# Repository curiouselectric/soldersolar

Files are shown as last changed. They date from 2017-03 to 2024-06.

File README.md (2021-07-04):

# Solder Solar
Design and instructions for a simple DIY solar powered torch.

# Overview
This is a very simple soldering kit to build a solar powered torch.
The unit has a small solar panel which recharges an ultra-capacitor.
There are two LEDs, one white and one red, which are powered by the energy in the ultra-capacitor.

The ultra-capacitor is 0.47F which stores enough charge for around 20 mins of white light, or around 1 hour of red light.

This kit is designed as an introduction to solar power and also soldering.

This kit can also be used as a small power supply for other projects (requiring a 3-5.5V power supply). This could be used for very low power monitoring nodes.

This repository contains:

* Instructions
* Schematics 
* PCB design
* Parts list

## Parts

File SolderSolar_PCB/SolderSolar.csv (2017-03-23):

Reference | Value | Footprint | Datasheet
C1 | 0.47F | REInnovationFootprint:C_0_47F_SuperCap
D1 | 1N5819 | REInnovationFootprint:TH_Diode_1
D2 | RED | REInnovationFootprint:TH_LED-5MM_larg_pad_90degrees
D3 | WHITE | REInnovationFootprint:TH_LED-5MM_larg_pad_90degrees
P1 | SOLAR_V | matts_components:SIL-2_wide_lg_pad
P2 | LOGO1 | CuriousElectric3:CEC_Globe_10mm_FCU
P3 | LOGO2 | CuriousElectric3:TCEC_Words_13mm
P4 | PCB | REInnovationFootprint:PV_50x30mmEdgeCut
P5 | LOGO3 | CuriousElectric3:TCEC_Words_13mm FCu
R1 | 330 | REInnovationFootprint:TH_Resistor_1
R2 | 120 | REInnovationFootprint:TH_Resistor_1
SC1 | PV_CELL | REInnovationFootprint:PV_50x30mm_NoOutline
SW1 | RED | REInnovationFootprint:TH_FRONT_SW
SW2 | WHITE | REInnovationFootprint:TH_FRONT_SW

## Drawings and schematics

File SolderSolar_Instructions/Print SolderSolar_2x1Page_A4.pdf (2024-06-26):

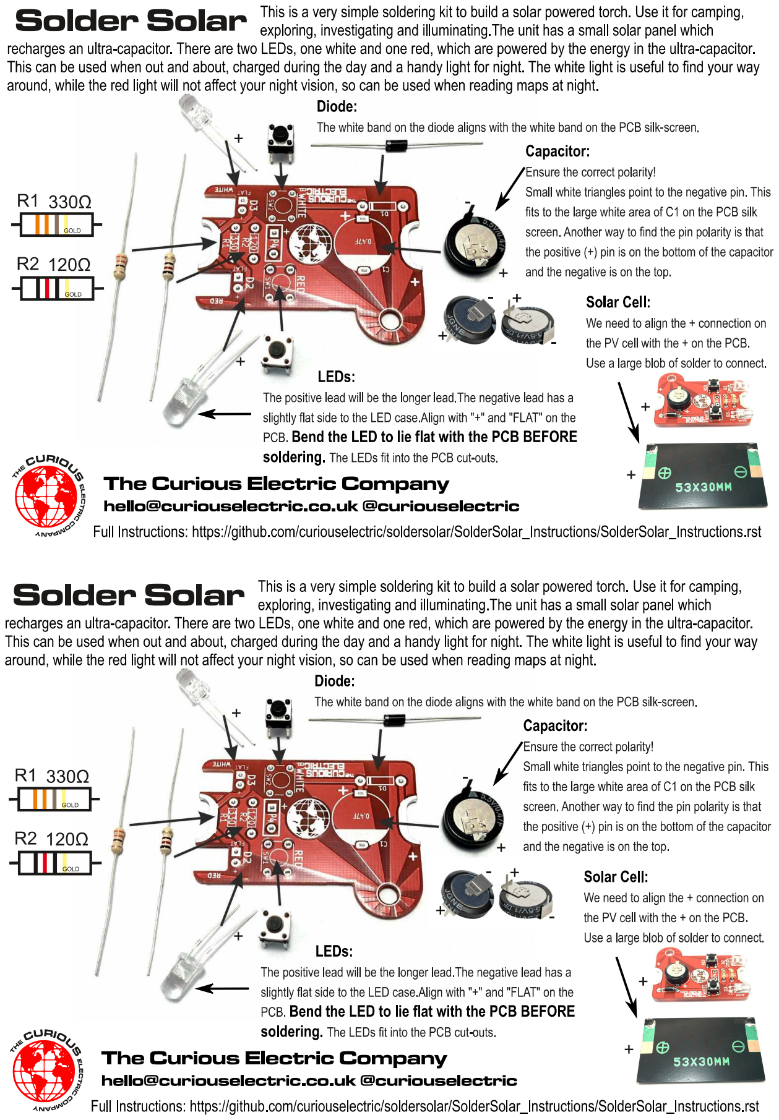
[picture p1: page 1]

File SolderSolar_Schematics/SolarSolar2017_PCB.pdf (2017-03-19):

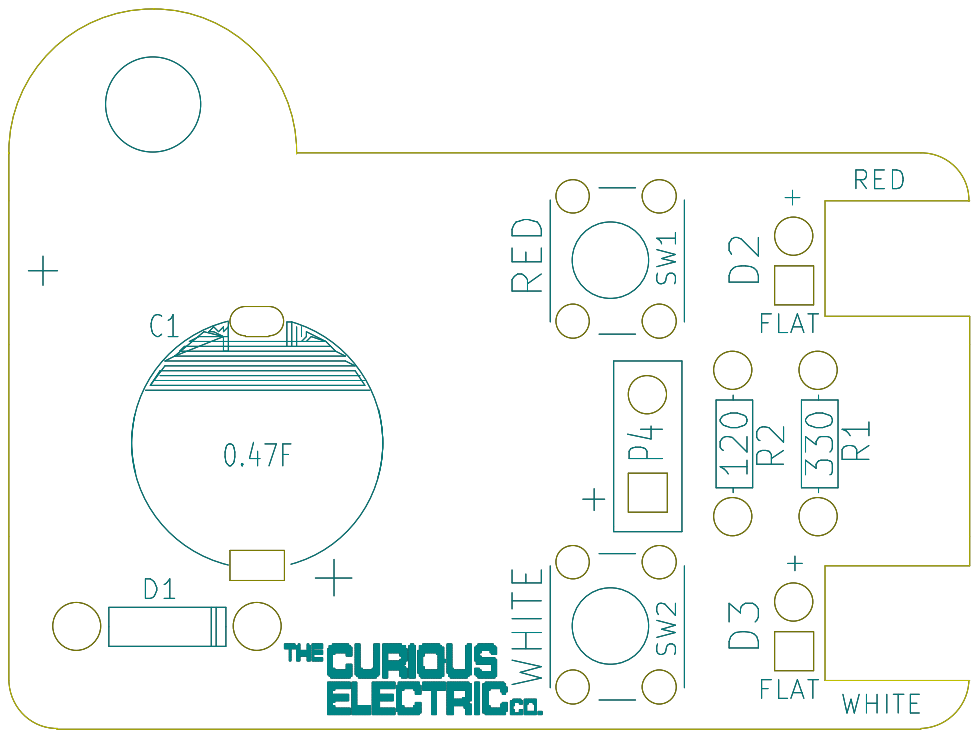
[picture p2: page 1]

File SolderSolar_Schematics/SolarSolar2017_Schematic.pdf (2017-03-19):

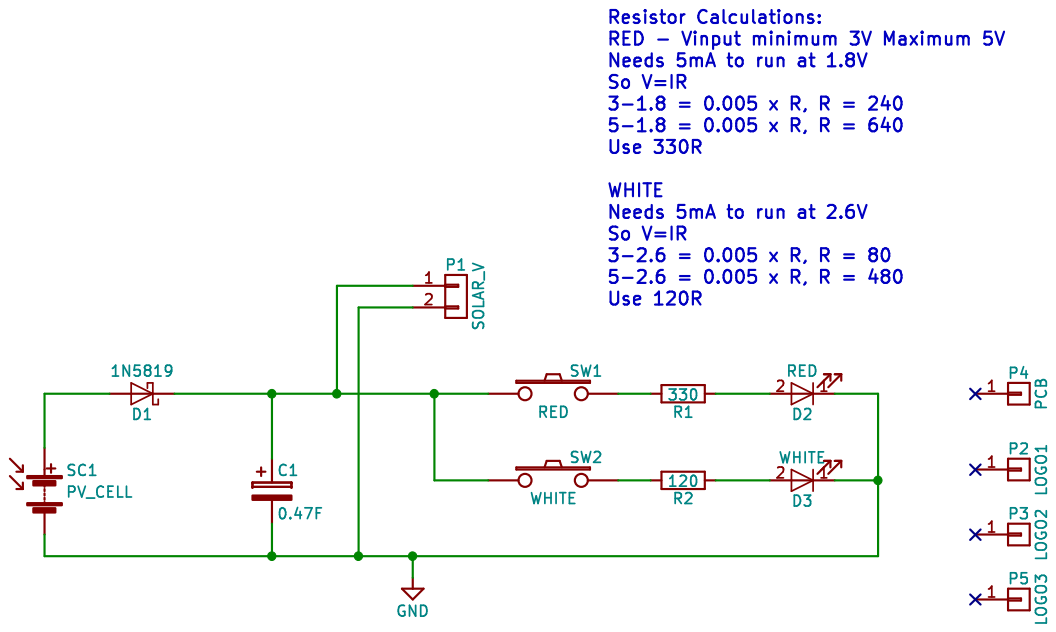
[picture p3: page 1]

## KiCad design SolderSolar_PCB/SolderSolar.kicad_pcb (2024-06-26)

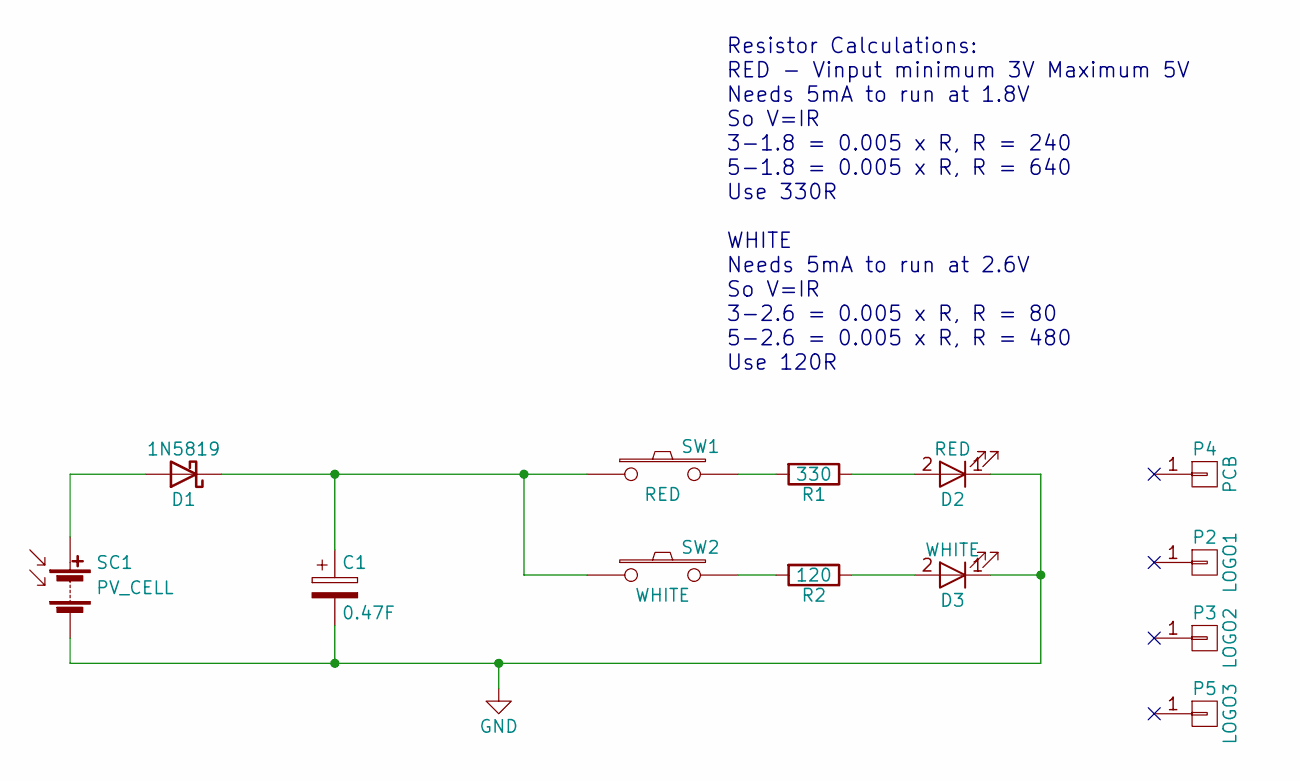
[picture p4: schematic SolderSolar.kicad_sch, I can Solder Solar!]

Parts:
C1: 0.47F; C_0_47F_SuperCap_3POS
D1: 1N5819; TH_Diode_1
D2: RED; TH_LED-5MM_larg_pad_90degrees
D3: WHITE; TH_LED-5MM_larg_pad_90degrees
P2: LOGO1; 2019_011_16_CuriousElectricCompany_Logo_Round_Logo_No_words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
P3: LOGO2; TCEC_Words_13mm
P4: PCB
P5: LOGO3; TCEC_Words_13mm FCu
R1: 330; TH_Resistor_1
R2: 120; TH_Resistor_1
SC1: PV_CELL; PV_50x30mm_NoOutline_v2
SW1: RED; TH_FRONT_SW
SW2: WHITE; TH_FRONT_SW

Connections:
GND: C1.2, D2.1 (K), D3.1 (K), SC1.2 (-)
unnamed: D1.2 (A), SC1.1 (+)
unnamed: C1.1, D1.1 (K), SW1.1, SW2.1
unnamed: D2.2 (A), R1.1
unnamed: D3.2 (A), R2.1
unnamed: R1.2, SW1.2
unnamed: R2.2, SW2.2

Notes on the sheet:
Resistor Calculations: RED - Vinput minimum 3V Maximum 5V Needs 5mA to run at 1.8V So V=IR 3-1.8 = 0.005 x R, R = 240 5-1.8 = 0.005 x R, R = 640 Use 330R WHITE Needs 5mA to run at 2.6V So V=IR 3-2.6 = 0.005 x R, R = 80 5-2.6 = 0.005 x R, R = 480 Use 120R

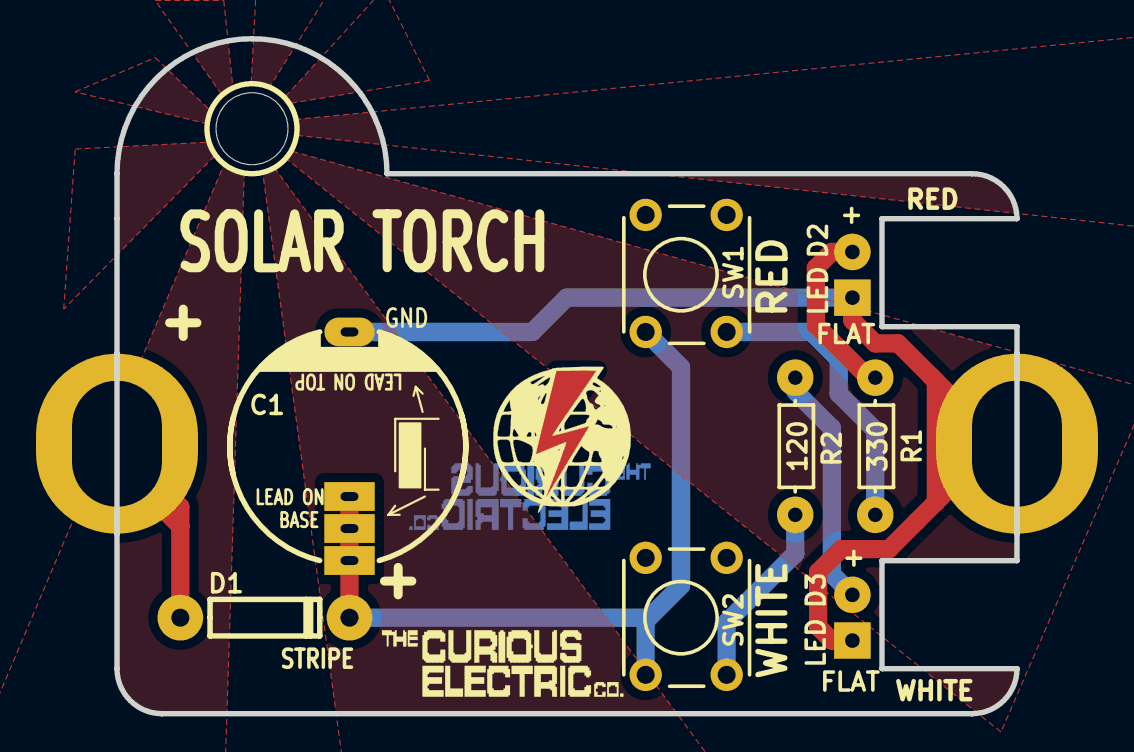
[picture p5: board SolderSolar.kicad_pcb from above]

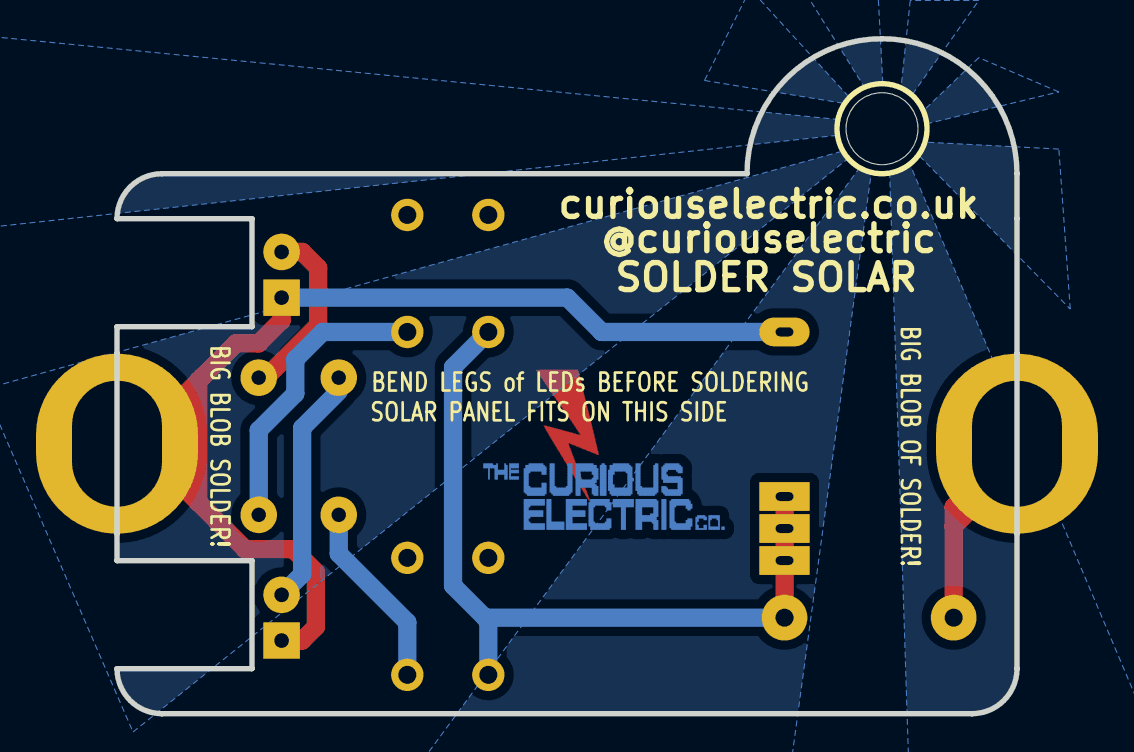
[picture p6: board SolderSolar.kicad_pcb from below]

Board: 2 copper layers, 50.0 x 37.5 mm, 13 parts (2 on the bottom side), 7 nets.

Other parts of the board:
P1: SOLAR_V; PV_50x30mmEdgeCut

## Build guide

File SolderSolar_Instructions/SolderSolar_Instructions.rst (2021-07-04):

Solder Solar
============

Design and instructions for a simple DIY solar powered torch.

This kit is designed as a **"Learn to Solder"** kit and as an introduction to **solar power**.

*By: Matthew Little*

*Date: 17th Feb 2017*

*email: hello@curiouselectric.co.uk*

Overview
-------
This is a very simple soldering kit to build a solar powered torch. Use it for camping, exploring, investigating and illuminating.

The unit has a small solar panel which recharges an ultra-capacitor.
There are two LEDs, one white and one red, which are powered by the energy in the ultra-capacitor.

This can be used when out and about, charged during the day and a handy light for night. The white light is useful to find your way around, while the red light will not affect your night vision, so can be used when reading map at night.

The ultra-capacitor is 0.47F which stores enough charge for around 20 minutes of white light, or around 1 hour of red light.

This kit can also be used as a small power supply for other projects (requiring a 3-5.5V power supply). This could be used for very low power monitoring nodes.

Kit Contents
------------

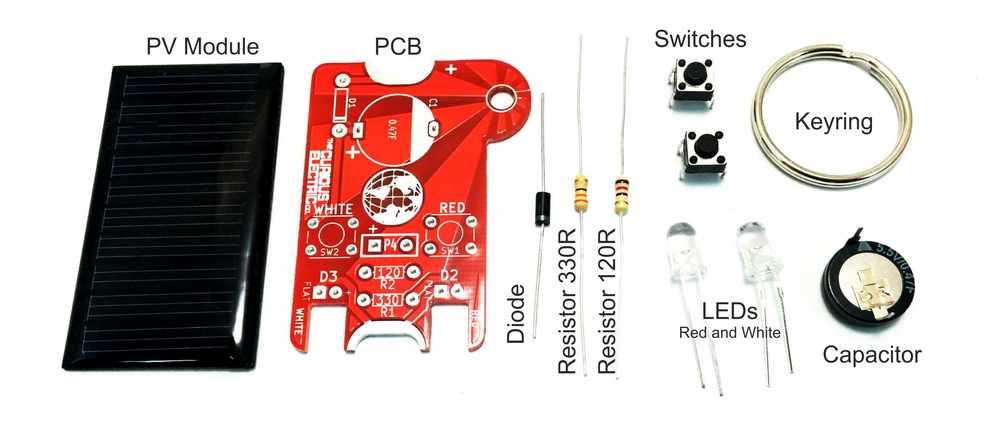
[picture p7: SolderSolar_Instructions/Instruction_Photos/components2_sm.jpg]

   
This kit contains the following parts:

+------+-----------------+--------------------------+
| REF  | Description     | Details                  |
+======+=================+==========================+
| C1   | Ultra-Capacitor | 0.47F Electrolytic       |
+------+-----------------+--------------------------+
| D1   | Diode           |                          |
+------+-----------------+--------------------------+
| D2   | LED Red         |                          |
+------+-----------------+--------------------------+
| D3   | LED White       |                          |
+------+-----------------+--------------------------+
| R1   | Resistor        |                          |
+------+-----------------+--------------------------+
| R2   | Resistor        |                          |
+------+-----------------+--------------------------+
| SC1  | Solar PV Panel  |                          |
+------+-----------------+--------------------------+
| SW1  | Switch          |                          |
+------+-----------------+--------------------------+
| SW2  |  Switch         |                          |
+------+-----------------+--------------------------+
| PCB  |  Circuit board  |                          |
+------+-----------------+--------------------------+

This photo shows where each of the components is placed on the PCB.

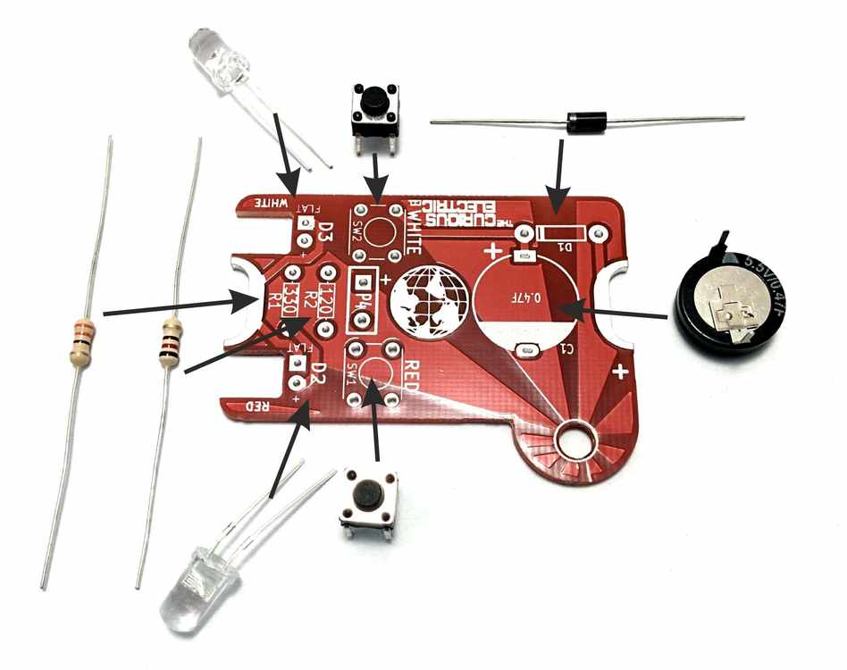
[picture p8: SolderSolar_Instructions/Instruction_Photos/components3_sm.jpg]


Tools Required
--------------
The following tools will be required:

+-----------------+--------------------------+
| Tool            | Description              |
+=================+==========================+
| Soldering Iron  | 25W+ is best             |
+-----------------+--------------------------+
| Solder          | I use lead-free solder   |
+-----------------+--------------------------+
| Side-cutter     | For cutting excess leads |
+-----------------+--------------------------+

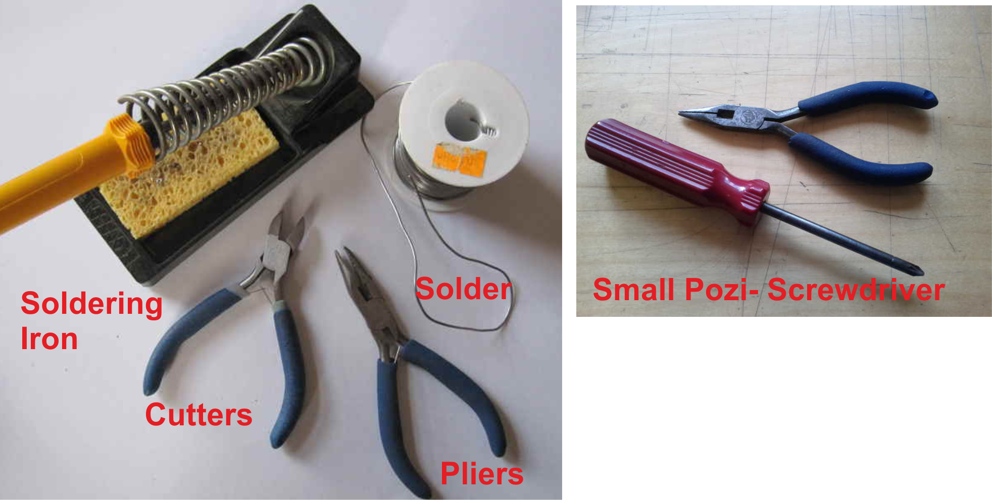
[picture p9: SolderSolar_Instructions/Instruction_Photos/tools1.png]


A useful guide for learning to solder is available here:

https://cdn.shopify.com/s/files/1/0943/8168/files/soldercomic.pdf

And a more detaileld guide is available here:

https://cdn.shopify.com/s/files/1/0943/8168/files/FullSolderComic_EN.pdf

Step 1: Solder Resistors
------------------------
There are two resistor to solder into the areas marked R1 and R2. These control the current into the LEDs and hence their brightness.

+------+-----------------+--------------------------+
| REF  | Description     | Details                  |
+======+=================+==========================+
| R1   | 330R resistor   | Orange-Orange-Brown-Gold |
+------+-----------------+--------------------------+
| R2   | 120R resistor   | Brown-Red-Black-Gold     |
+------+-----------------+--------------------------+

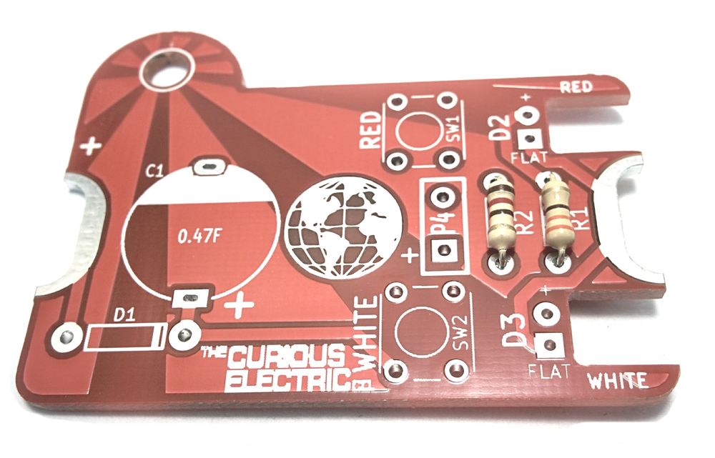
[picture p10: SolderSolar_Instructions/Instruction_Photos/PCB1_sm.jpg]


Step 2: Solder Diode
------------------------

There is one diode to solder into the holes marked D1. This is a 1N5819 Schottky diode, which is suitable for up to 1A and has a low voltage drop.
The diode allow current to pass from the solar cell to the capacitor, but not allow current to flow back to the solar cell.
This diode **must** be inserted with the correct orientation. The white band on the diode must align with the thicker white band on the PCB silk-screen.

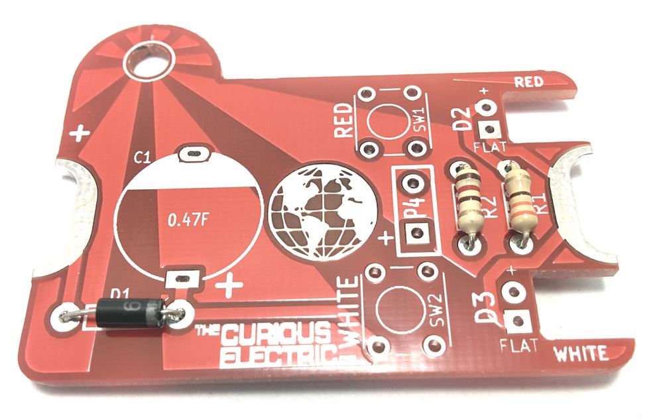
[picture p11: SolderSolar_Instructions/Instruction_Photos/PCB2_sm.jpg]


Info: The data sheet for the diode is here: https://www.diodes.com/assets/Datasheets/ds23001.pdf

Step 3: Solder Switches
------------------------
There are two switches to solder in locations SW1 and SW2.

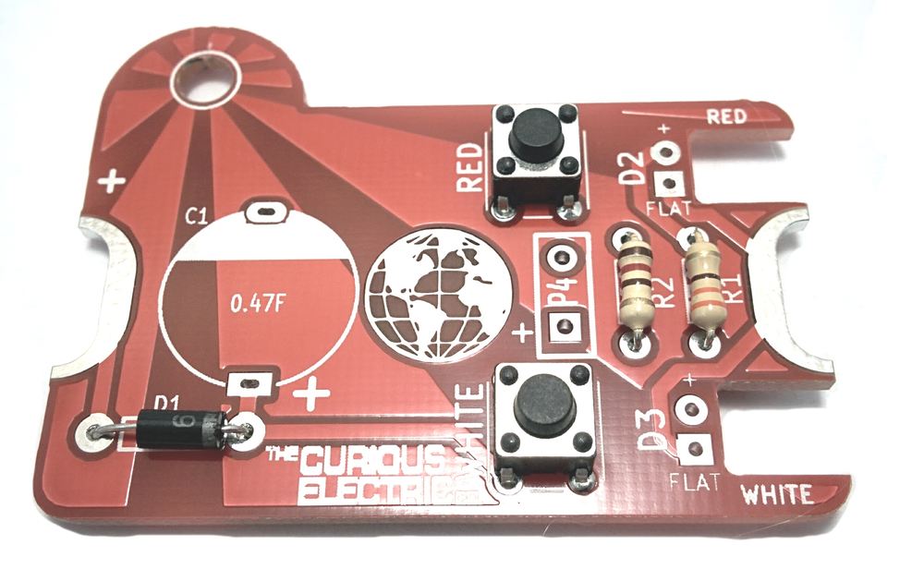
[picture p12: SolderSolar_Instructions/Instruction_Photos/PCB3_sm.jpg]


Step 4: Solder LEDs
------------------------
There are two LEDs to solder - one white and one red. These look very similar, but the red LED will have a label on it. Do not mix these up when the label taken off.

It is best to solder the white LED first, then take the label off the red LED and solder that.
You must ensure correct polarity of these LEDs.

The positive lead will be the longer lead. The negative lead has a slightly flat side to the LED case. These should align with the markings "+" and "FLAT" on the PCB.

The LEDs are designed to be bent down to align with the PCB into the cut-outs.
Please see photos for clarification.

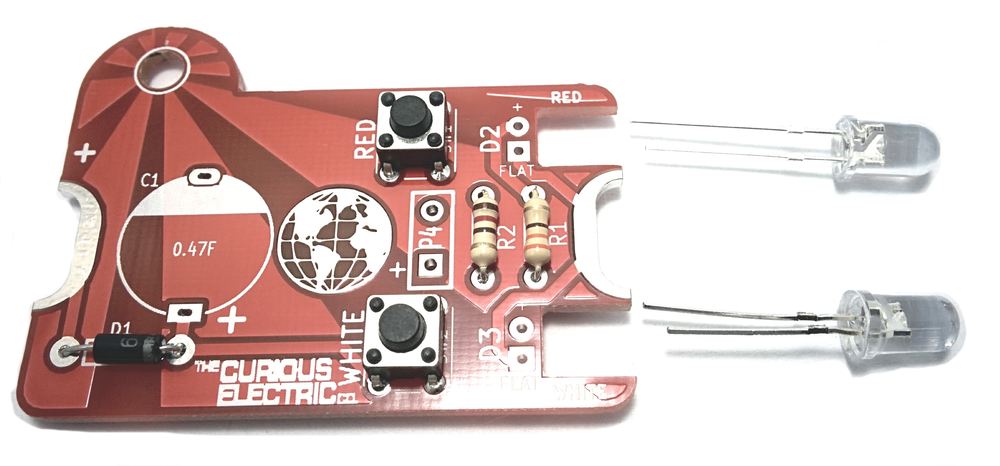
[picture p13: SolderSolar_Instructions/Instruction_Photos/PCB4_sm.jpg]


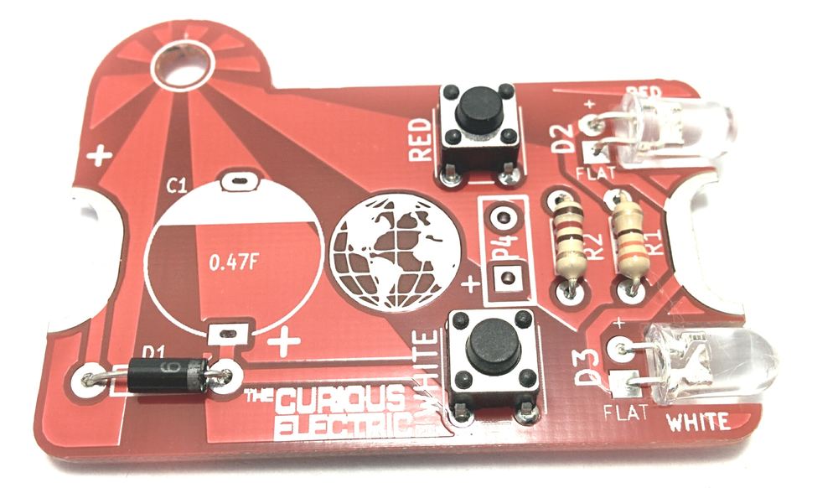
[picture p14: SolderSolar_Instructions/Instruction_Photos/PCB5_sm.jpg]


Step 5: Solder Capacitor
------------------------
The capacitor is a 0.47F ultra-capacitor. This is used to store the energy from the solar cell so it can be used later.
It is an electrolytic capacitor and you **must ensure the correct polarity**.

There are some small white triangles on the capacitor which indicate the negative pin. This pin must align with the large white area of C1 on the PCB silk screen.

Another way to find the pin polarity is that the positive (+) pin is on the bottom of the capacitor and the negative is on the top.
Please see photos for clarification.

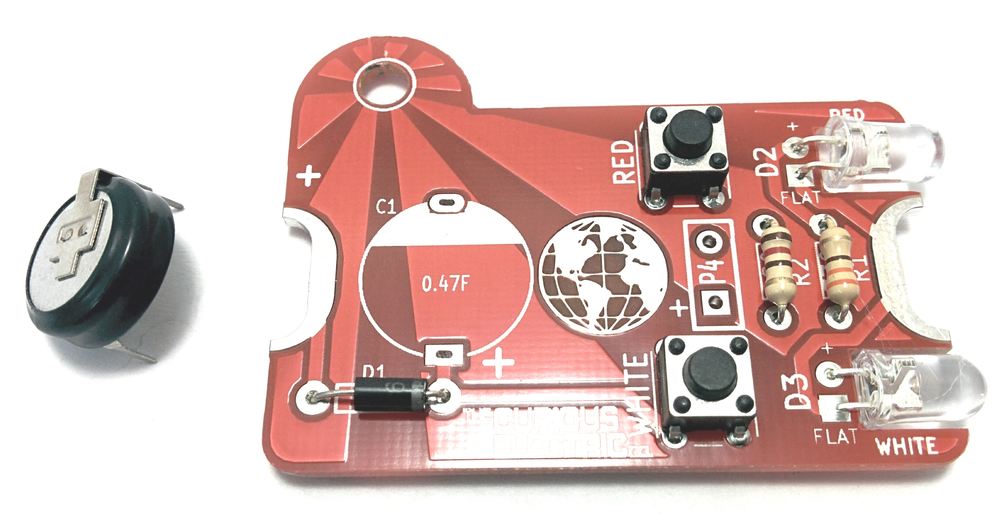
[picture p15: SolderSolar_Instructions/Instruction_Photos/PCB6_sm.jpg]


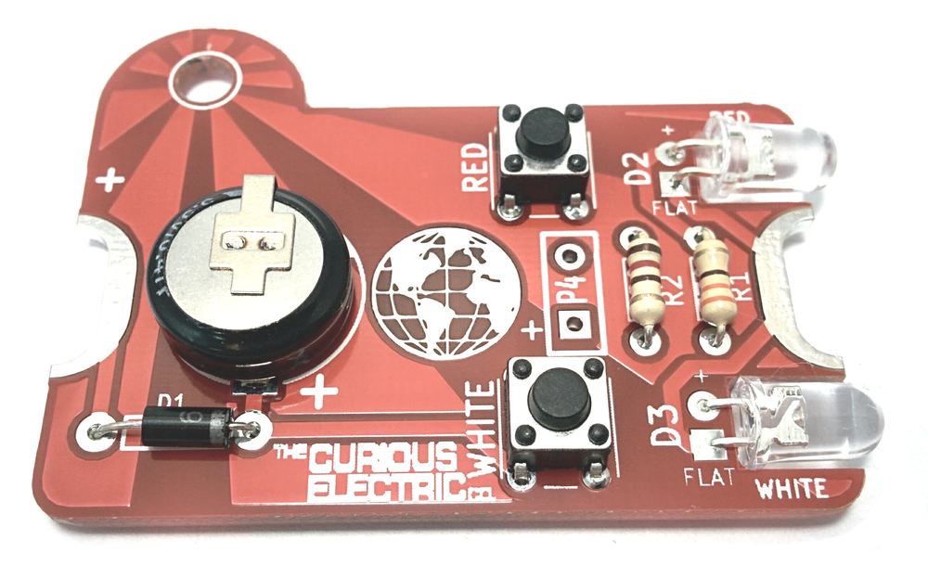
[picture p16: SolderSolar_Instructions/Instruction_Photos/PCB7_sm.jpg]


Step 6: Solder PV Cell
------------------------
The PV cell is actually a module comprised of a number of small solar PV cells. This unit has a maximum output of 5.5V and a maximum current of 30mA under ideal conditions.

The solar cell is attached to the back of the PCB and so will cover the soldering already done - please **double check** your soldering here and ensure there are not any bad connections or solder short circuits.

We need to align the + connection on the PV cell with the + on the PCB.

We need to add quite a lot of solder to make this conenction. It is best to put a blob of solder on the PV cell pad, then leave it to cool. Then align the PV cell and add more solder until the connection is made to the contacts on the edge of the PCB.

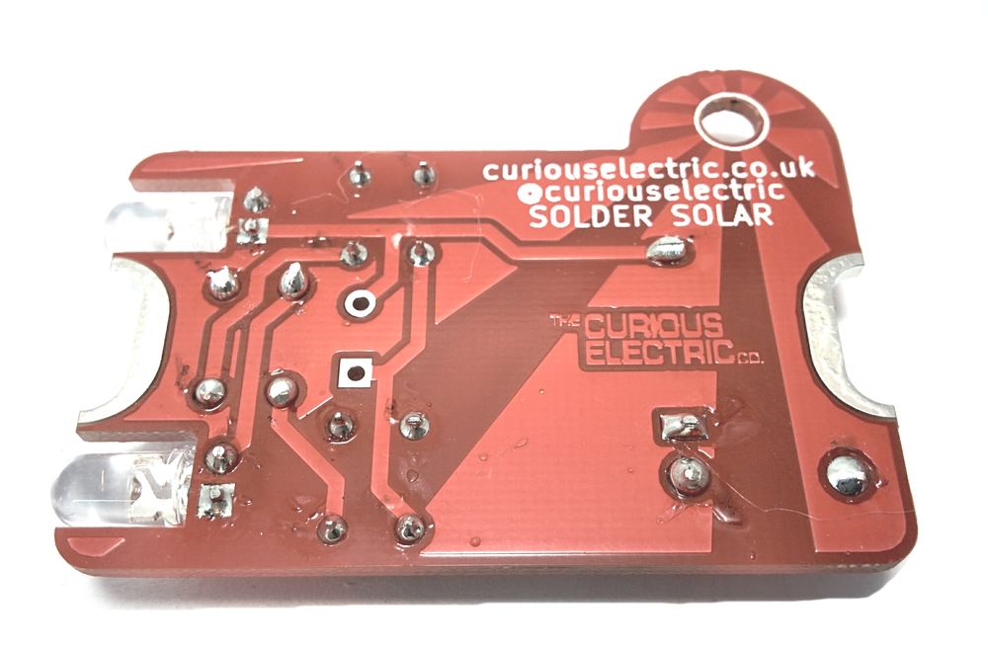
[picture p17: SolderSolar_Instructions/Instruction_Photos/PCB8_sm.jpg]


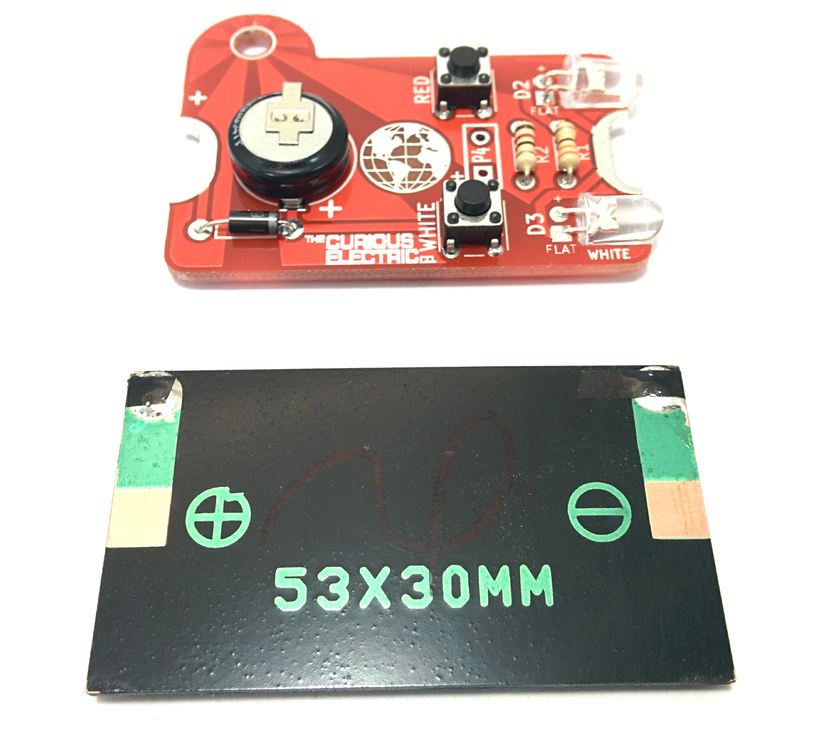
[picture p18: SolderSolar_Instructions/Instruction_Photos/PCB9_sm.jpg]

   
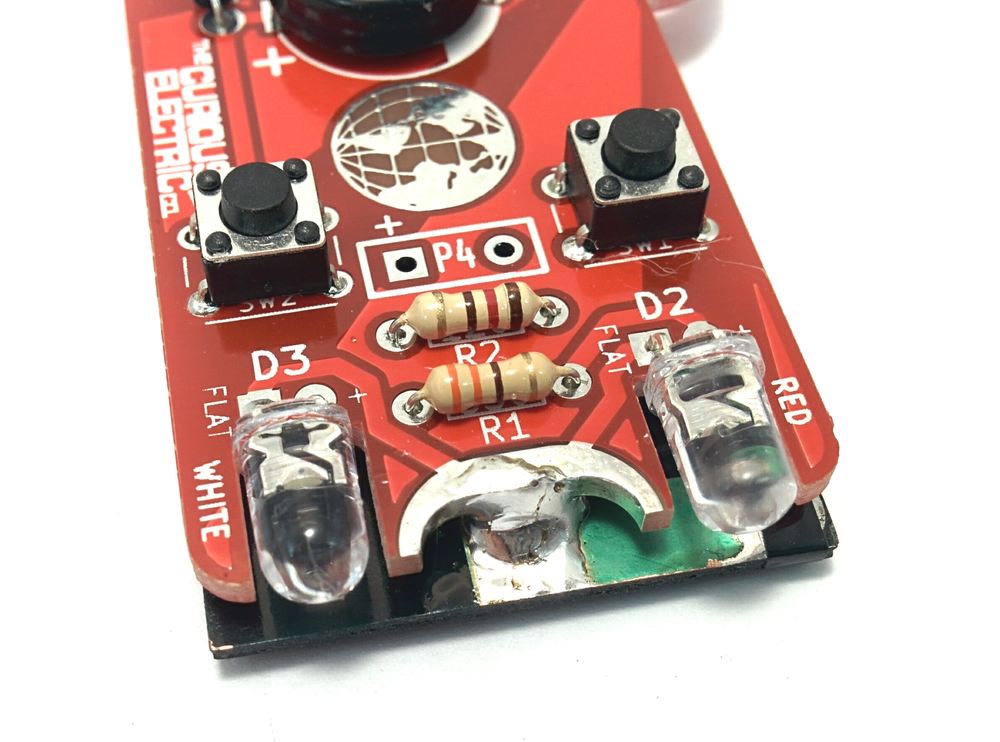
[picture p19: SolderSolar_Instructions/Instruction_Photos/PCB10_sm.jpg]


Step 7: Attach Key-ring
------------------------
If used, the key-ring can be bent out slightly and fitted into the hole on the side of the PCB.

This is designed to help clip it onto a back-pack etc. We would suggest not using this with keys, as the metal keys might short circuit the components and cause a problem.

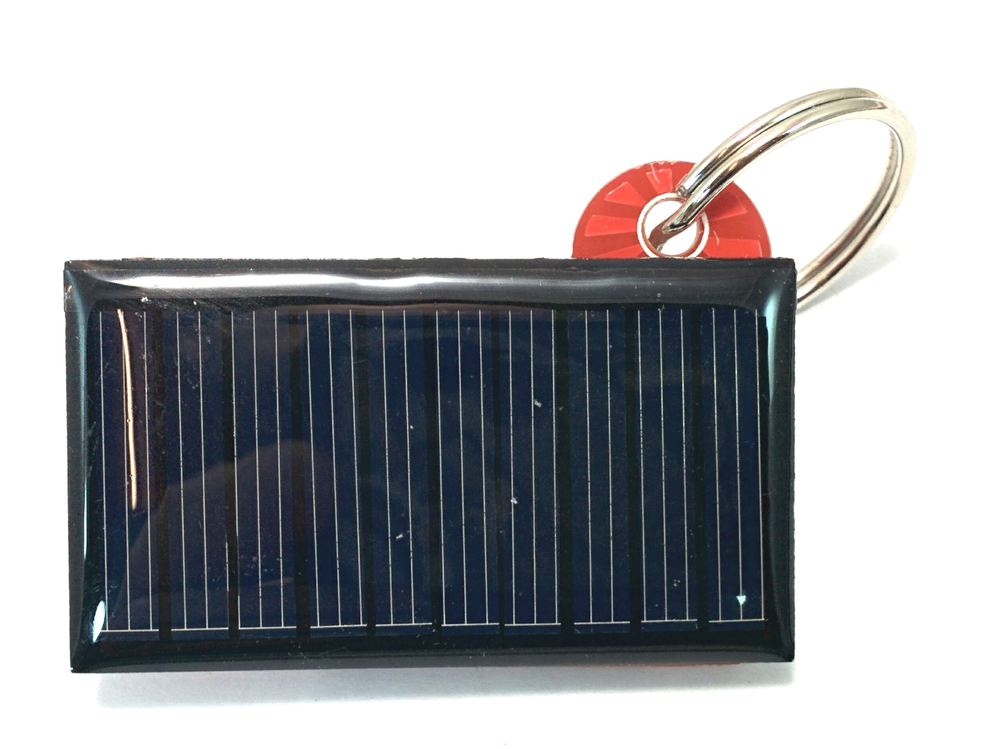
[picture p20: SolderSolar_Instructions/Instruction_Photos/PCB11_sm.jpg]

   
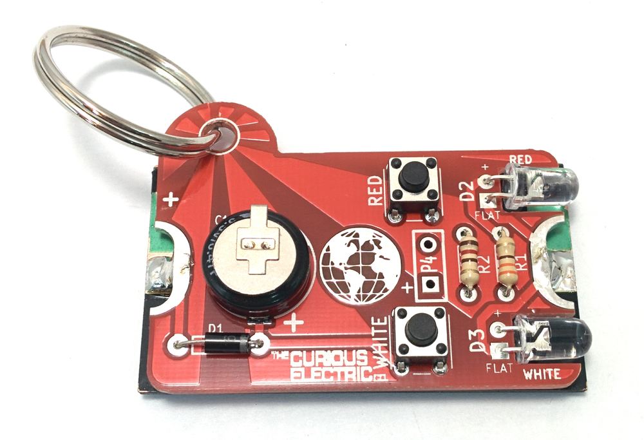
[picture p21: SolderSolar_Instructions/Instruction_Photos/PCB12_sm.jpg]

   
Step 8: Finished!
------------------------
Place the unit in bright sunlight for a while (at least 10mins).
When pressed, the switches should control each LED.

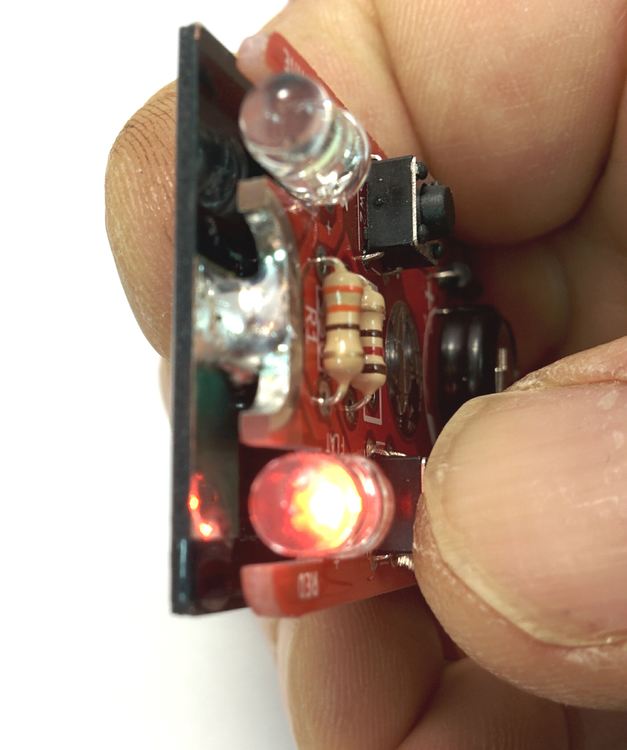
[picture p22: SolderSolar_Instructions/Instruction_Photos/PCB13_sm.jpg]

   
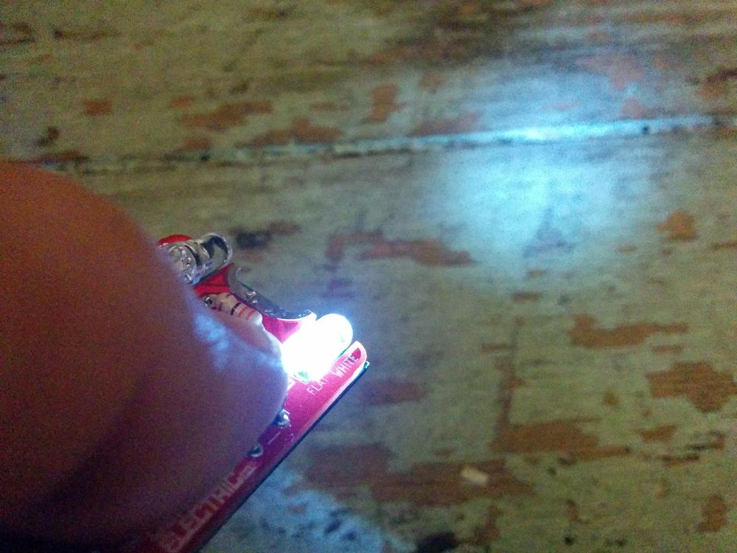
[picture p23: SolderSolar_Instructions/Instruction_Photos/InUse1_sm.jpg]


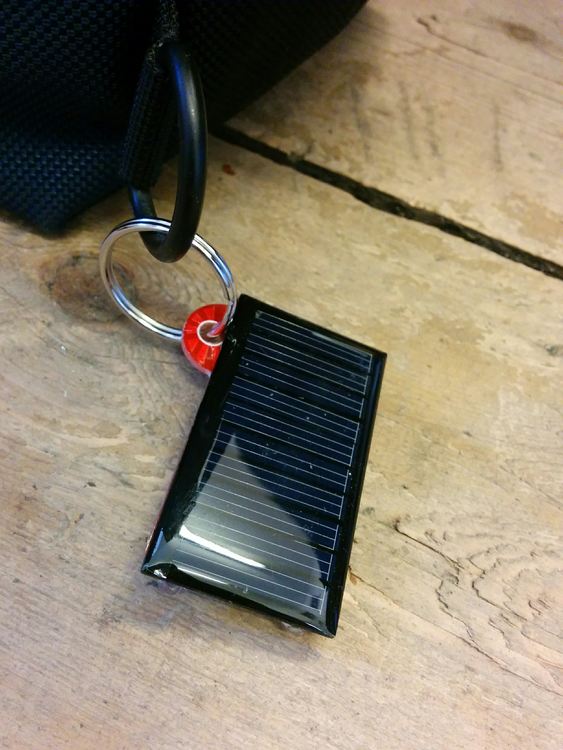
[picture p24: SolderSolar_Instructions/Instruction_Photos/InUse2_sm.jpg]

   
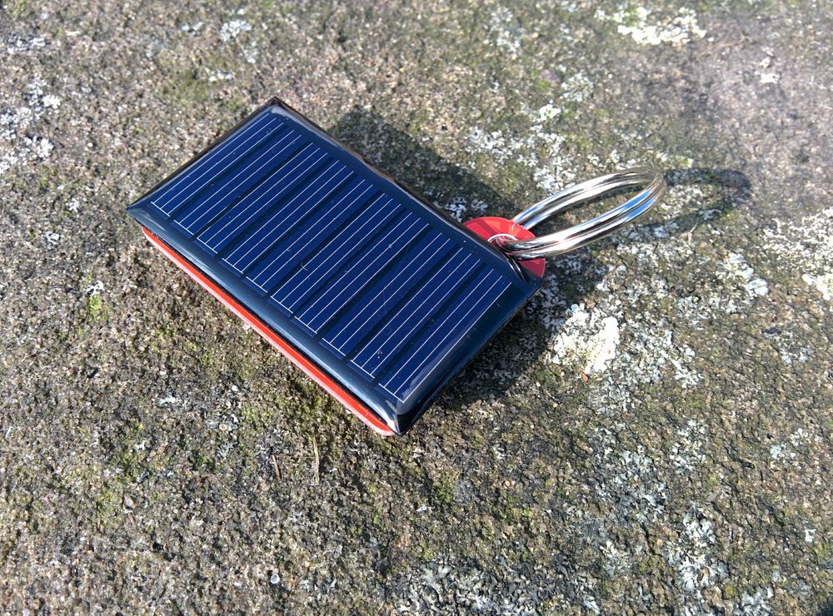
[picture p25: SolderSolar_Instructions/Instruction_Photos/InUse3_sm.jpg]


Going Further
----------------------
This unit is also designed to be used as a solar power unit for very low power applications. Connections to P4 are to the terminals of the ultra-capacitor and these can be used to power other projects.
Remember that the voltage can vary from 0V (when totally discharged) up to 5.3V (when totally charged). The attached circuit must be able to withstand this range of voltages.

Troubleshooting
--------------------
This ciruit is relatively simple and designed for the beginner. There are four items which have a polarity and the circuit will not work if any of the following are places the wrong way around:
- Diode
- LEDs
- Capacitor
- PV Cell

Please double check these in case of any issues.

Please also double check the soldering to ensure that there are no short circuits (solder connecting two pads) or 'dry joints' (which do not have enough solder or are not clean).

Circuit Schematic
-------------------
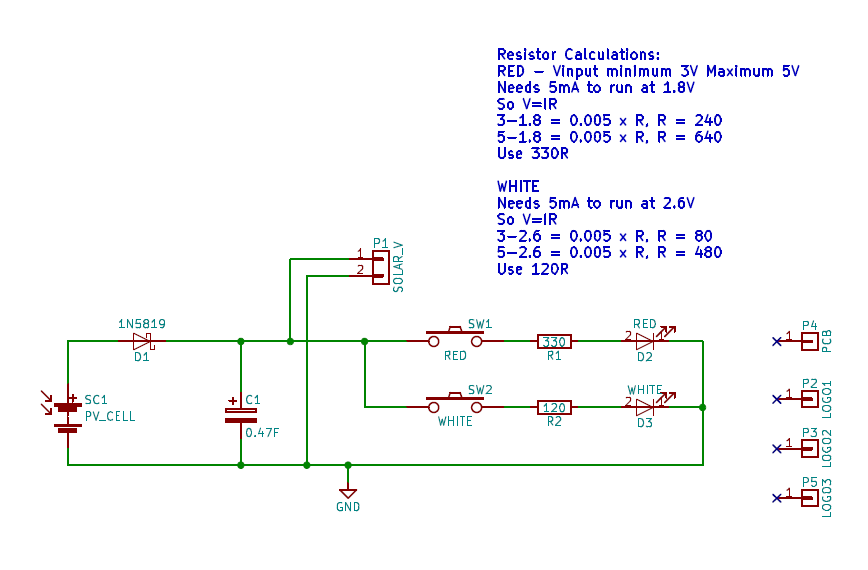
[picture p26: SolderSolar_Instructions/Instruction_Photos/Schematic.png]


PCB overview
------------
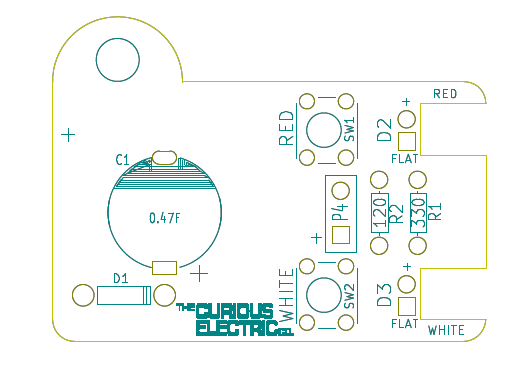
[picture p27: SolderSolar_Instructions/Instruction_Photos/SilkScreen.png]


Suppliers Information
----------------------
We would like you to be happy with this kit. If you are not happy for any reason then please contact us and we will help to sort it out.

Please email **hello@curiouselectric.co.uk** with any questions or comments or please tweet us at **@curiouselectric**

If any parts are missing from your kit then please email **hello@curiouselectric.co.uk** with details and, if possible, where the kit was purchased.

More technical information can be found via **www.curiouselectric.co.uk**

The GITHUB repository for all these files is: **https://github.com/curiouselectric/soldersolar**

This kit has been designed and produced by:

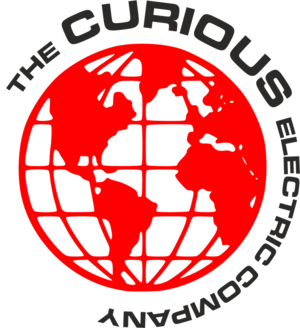
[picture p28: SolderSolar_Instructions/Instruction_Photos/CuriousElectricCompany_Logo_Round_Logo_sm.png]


..

   The Curious Electric Company
   
   hello@curiouselectric.co.uk
   
   www.curiouselectric.co.uk

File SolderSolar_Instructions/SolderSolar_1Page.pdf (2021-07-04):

R1 330Ω

## R2 120ΩGOLD

This is a very simple soldering kit to build a solar powered torch. Use it for camping, exploring, investigating and illuminating. The unit has a small solar panel which recharges an ultra-capacitor. There are two LEDs, one white and one red, which are powered by the energy in the ultra-capacitor.
This can be used when out and about, charged during the day and a handy light for night. The white light is useful to find your way around, while the red light will not affect your night vision, so can be used when reading maps at night.

Capacitor:
Ensure the correct polarity.!
Small white triangles indicate the negative pin. This fits to the large white area of C1 on the PCB silk screen.
Another way to find the pin polarity is that the positive (+) pin is on the bottom of the capacitor and the negative is on the top.

Solar Cell:
We need to align the + connection on the PV cell with the + on the PCB.
LEDs: | Use a large blob of solder to connect.
The positive lead will be the longer lead.
The negative lead has a slightly flat side
to the LED case.
Align with "+" and "FLAT" on the PCB. The LEDs fit into the PCB cut-outs.

Diode:
The white band on the diode aligns with the white band on the PCB silk-screen.

# Solder Solar

The Curious Electric Company Hopkinson, 21 Station Street, Nottingham, NG2 3AJ
curiouselectric.co.uk
@curiouselectric
Full Instructions:

https://github.com/curiouselectric/soldersolar/SolderSolar_Instructions/SolderSolar_Instructions.rst GOLD

+

+

+

+

+

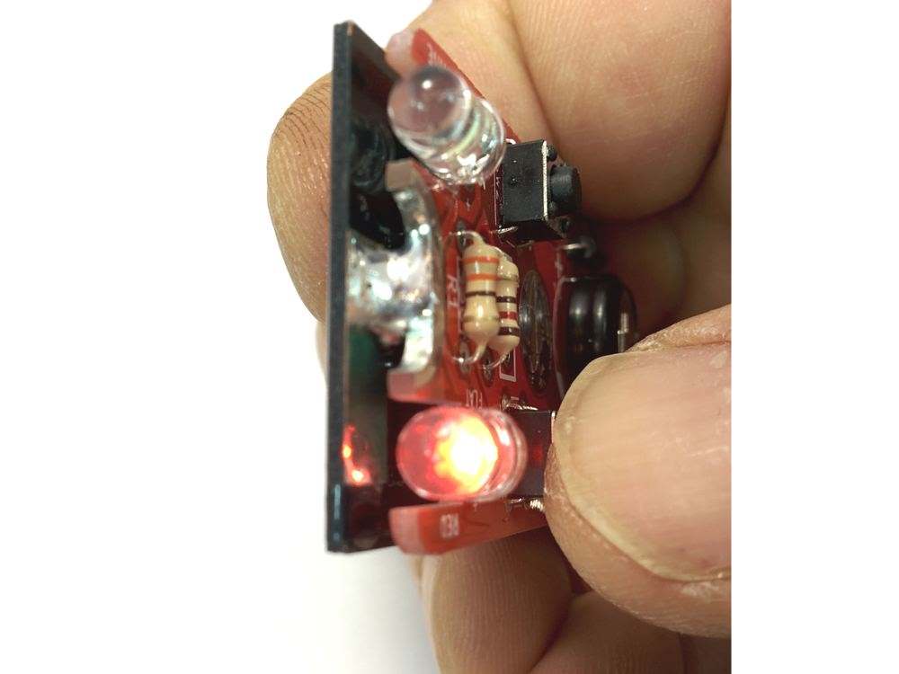
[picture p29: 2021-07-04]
SolderSolar_Instructions/Instruction_Photos/PCB13_sm_1000x750.jpg

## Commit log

2017-03-19 First Commit
    PCB files, Hardware designs
    [SolderSolar2017-B.Cu.gbr, SolderSolar2017-B.Mask.gbr, SolderSolar2017-B.SilkS.gbr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]
2017-03-19 Updated Names
    Removed 2017 reference
    [SolderSolar-B.Cu.gbr, SolderSolar-B.Mask.gbr, SolderSolar-B.SilkS.gbr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]
2017-03-23 Updated instructions rst. First (bad) version
    [SolderSolar.csv]
2017-05-13 Update SolderSolar_Instructions.rst
    s/tringles/triangles/
2021-07-04 Updated PCB for KiCAD
    [SolderSolar-2019-01-11-22-13-11.sch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]
2023-01-22 updated to kicad 6. updated PCB
    [SolderSolar-B_Cu.gbr, SolderSolar-B_Mask.gbr, SolderSolar-B_SilkS.gbr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]
2024-06-26 Updated with new logo and instructions on PCB
    [SolderSolar-B_Cu.gbr, SolderSolar-B_Mask.gbr, SolderSolar-B_Silkscreen.gbr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]
2024-06-26 changed hole size for production
    [SolderSolar-B_Cu.gbr, SolderSolar-B_Mask.gbr, SolderSolar-B_Silkscreen.gbr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]
